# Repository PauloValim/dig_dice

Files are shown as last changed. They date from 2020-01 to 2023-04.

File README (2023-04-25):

Dado Digital usando CI´s da família TTL 74LS

A ideia deste projeto é servir como apoio às aulas da disciplina de circuitos digitais. Ao longo da disciplina, cada um dos blocos que compõem o dado digital será apresentado, de forma que, ao final, o aluno tenha um produto real e, além disso, tenha total entendimento de todos os detalhes do projeto.

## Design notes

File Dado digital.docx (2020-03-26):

Dado digital

Objetivo: implementar um circuito digital que permita efetuar o sorteio equivalente à face de um dado digital.

Descrição do projeto

Figura 1 – Diagrama de Blocos do Dado Digital

A Figura 1 ilustra o diagrama de blocos do Dado Digital. A base é um contador digital, que pode ser síncrono ou assíncrono, que efetua a contagem de 1 a 6 em binário. O bloco combinacional Decodificador é responsável por receber na entrado um valor binário entre 1 e 6 e gerar na saída o acionamento dos Leds correspondente a face de um dado. Para isto são usado 7 leds, conforme representado na figura 1. O circuito oscilador é responsável por gerar uma freqüência elevada (acima de 30 Hz) para que, uma vez fechada a CHAVE, o contador gere a sequência de 1 a 6 em uma velocidade que uma pessoa não consiga perceber que ela está ocorrendo (a impressão que se tem é que todos os leds estão ligados). Quando a chave é aberta o contador pára a contagem em um valor aleatório entre 1 e 6, equivalendo ao lançamento de um dado.

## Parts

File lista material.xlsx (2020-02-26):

Lista Material Dado Digital | característica encapsulamento | Quantidade
componente
74LS244 | CI/DIP | 1 | https://www.multcomercial.com.br/circuito-integrado-sn74ls244n-dip20-cod-loja-350-texas.html
74LS193 | CI/DIP | 1 | https://www.multcomercial.com.br/circuito-integrado-sn74ls193n-dip16-cod-loja-2141-fairchild.html
74LS10 | CI/DIP | 1 | https://www.multcomercial.com.br/circuito-integrado-sn74ls10n-dip14-renesas.html
74LS14 | CI/DIP | 1 | https://www.multcomercial.com.br/circuito-integrado-sn74ls14n-dip14-cod-loja-510-texas.html
MINI USB B SMD | conector USB/SMD | 1 | https://www.multcomercial.com.br/conector-mini-usb-femea-tipo-b-em-smd-5-vias-ds1104-b60sr.html
LED 5 mm |  | 7 | https://www.multcomercial.com.br/led-pisca-5mm-vermelho-difuso-l-517hd.html
150 ohms | resistor / SMD 0805 | 7 | https://www.multcomercial.com.br/resistor-smd-de-1-10-de-watt-0805-com-5-de-tolerancia-0r-a-10m.html
10 nF | capacitor SMD | 4 | http://sccomp.com.br/p-9307248-Capacitor-Ceramico-SMD-0805-10nF_50V-
22 pF | capacitor SMD | 1 | http://sccomp.com.br/p-9307254-Capacitor-Ceramico-SMD-0805-22pF_50V-
1k ohms | resistor / SMD 0805 | 1 | https://www.multcomercial.com.br/resistor-smd-de-1-10-de-watt-0805-com-5-de-tolerancia-0r-a-10m.html
chave tactil | 12x12x9.5 mm | 1 | https://www.baudaeletronica.com.br/chave-tactil-12x12x9-5mm-4-terminais.html
PCI | Placa Circuito Impresso

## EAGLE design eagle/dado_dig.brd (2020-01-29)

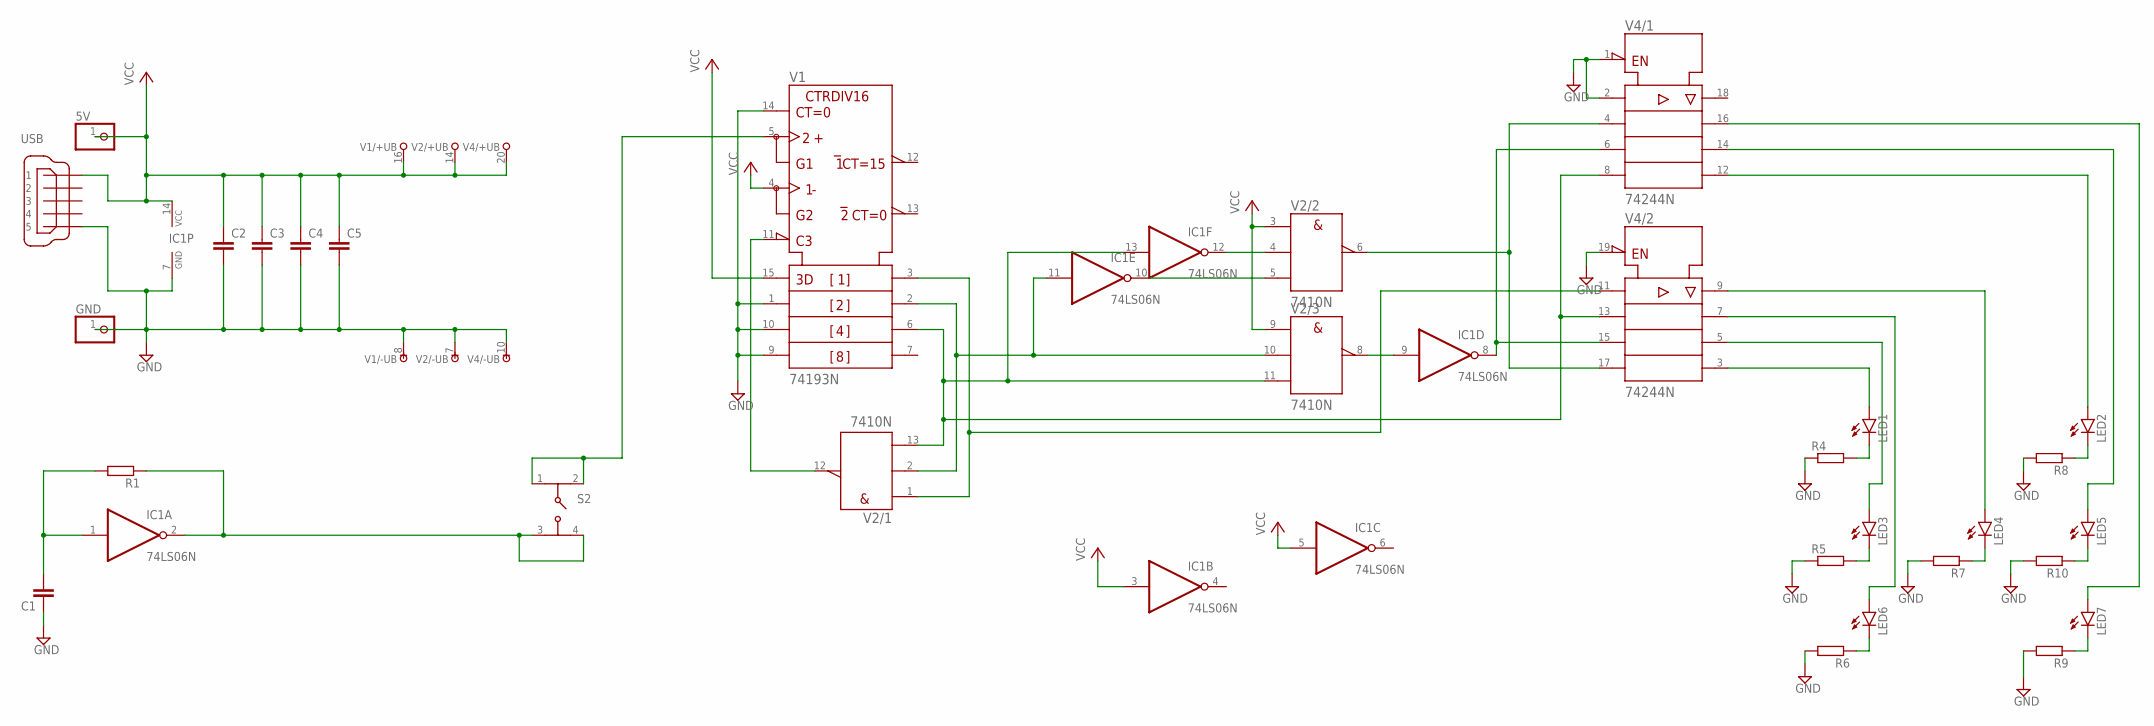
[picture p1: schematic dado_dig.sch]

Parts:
5V: PINHD-1X1; 1X01
C1, C2, C3, C4, C5: C-EUC0805K; C0805K
GND: PINHD-1X1; 1X01
IC1: 74LS06N; DIL14
LED1, LED2, LED3, LED4, LED5, LED6, LED7: LED5MM
R1, R4, R5, R6, R7, R8, R9, R10: R-EU_M0805; M0805
S2: 430456073736
USB: MINI-USB-32005-301; 32005-301
V1: 74193N; DIL16
V2: 7410N; DIL14
V4: 74244N; DIL20

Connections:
GND: C1.1, C2.2, C3.2, C4.2, C5.2, GND.1, IC1.7 (GND), R4.1, R5.1, R6.2, R7.2, R8.2, R9.2, R10.2, USB.5, V1.1 (B), V1.8 (-UB), V1.9 (D), V1.10 (C), V1.14 (CLR), V2.7 (-UB), V4.1 (!G), V4.2 (A1), V4.10 (-UB), V4.19 (!G)
unnamed: IC1.13 (I), V1.6 (QC), V2.11 (C), V2.13 (C), V4.8 (A4), V4.13 (A2)
unnamed: IC1.9 (I), V2.8 (Y)
unnamed: C1.2, IC1.1 (I), R1.2
unnamed: IC1.12 (O), V2.4 (B)
unnamed: IC1.2 (O), R1.1, S2.3 (2), S2.4
unnamed: V1.3 (QA), V2.1 (A), V4.11 (A1)
unnamed: IC1.10 (O), V2.5 (C)
unnamed: S2.1, S2.2 (3), V1.5 (UP)
unnamed: IC1.11 (I), V1.2 (QB), V2.2 (B), V2.10 (B)
unnamed: LED6.K (C), R6.1
unnamed: LED4.A, V4.9 (Y1)
unnamed: LED5.K (C), R10.1
unnamed: LED3.K (C), R5.2
unnamed: LED5.A, V4.14 (Y3)
unnamed: LED1.A, V4.3 (Y4)
unnamed: LED4.K (C), R7.1
unnamed: LED2.A, V4.12 (Y4)
unnamed: LED2.K (C), R8.1
unnamed: LED7.K (C), R9.1
unnamed: LED1.K (C), R4.2
unnamed: LED7.A, V4.16 (Y2)
unnamed: V1.11 (!LOAD), V2.12 (Y)
unnamed: LED6.A, V4.7 (Y2)
unnamed: V2.6 (Y), V4.4 (A2), V4.17 (A4)
unnamed: LED3.A, V4.5 (Y3)
unnamed: IC1.8 (O), V4.6 (A3), V4.15 (A3)
VCC: 5V.1, C2.1, C3.1, C4.1, C5.1, IC1.3 (I), IC1.5 (I), IC1.14 (VCC), USB.1, V1.4 (DOWN), V1.15 (A), V1.16 (+UB), V2.3 (A), V2.9 (A), V2.14 (+UB), V4.20 (+UB)

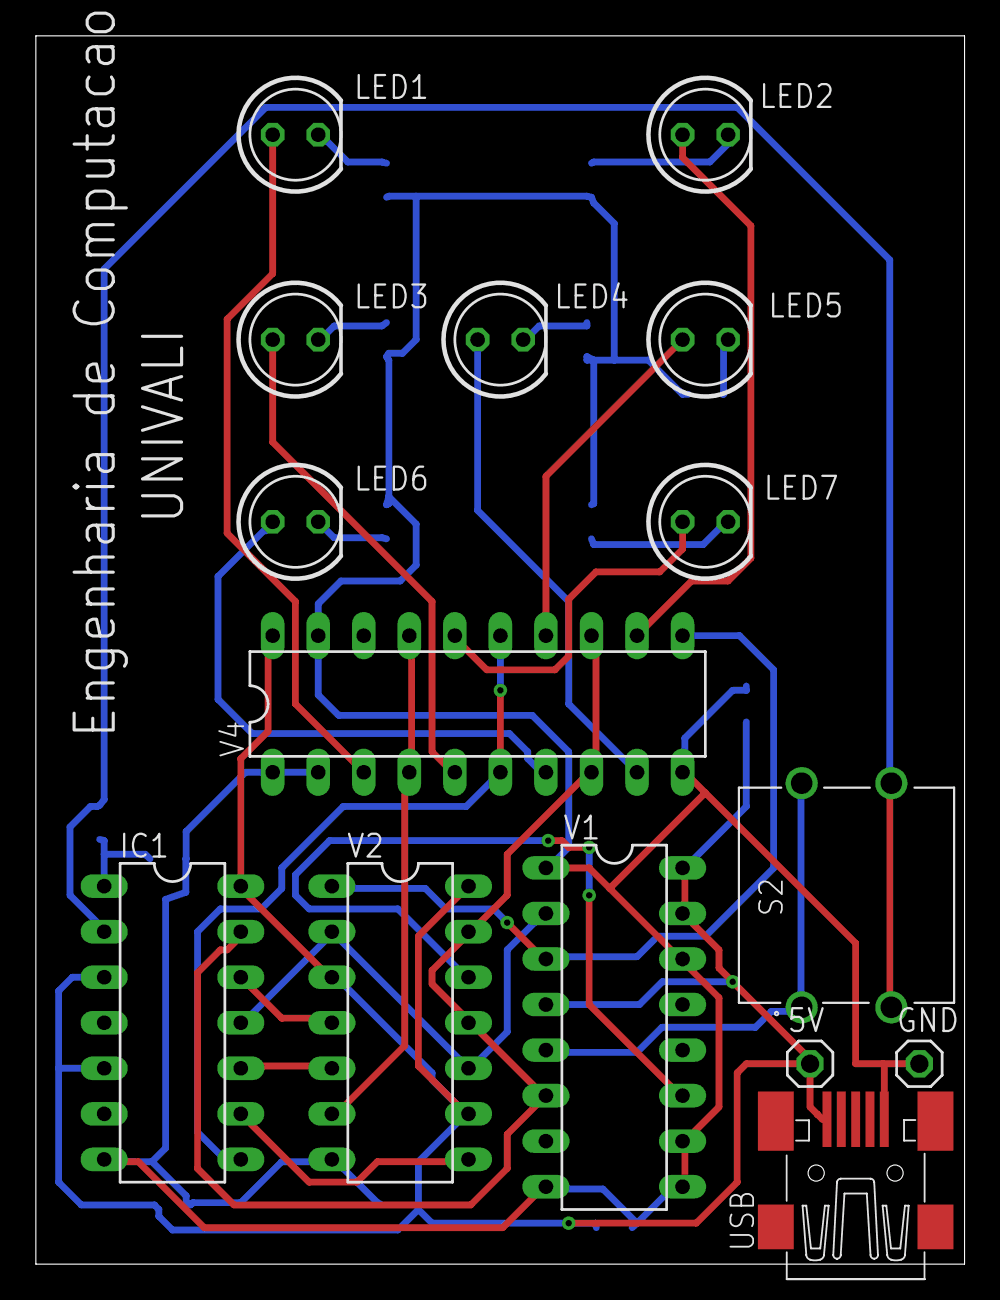
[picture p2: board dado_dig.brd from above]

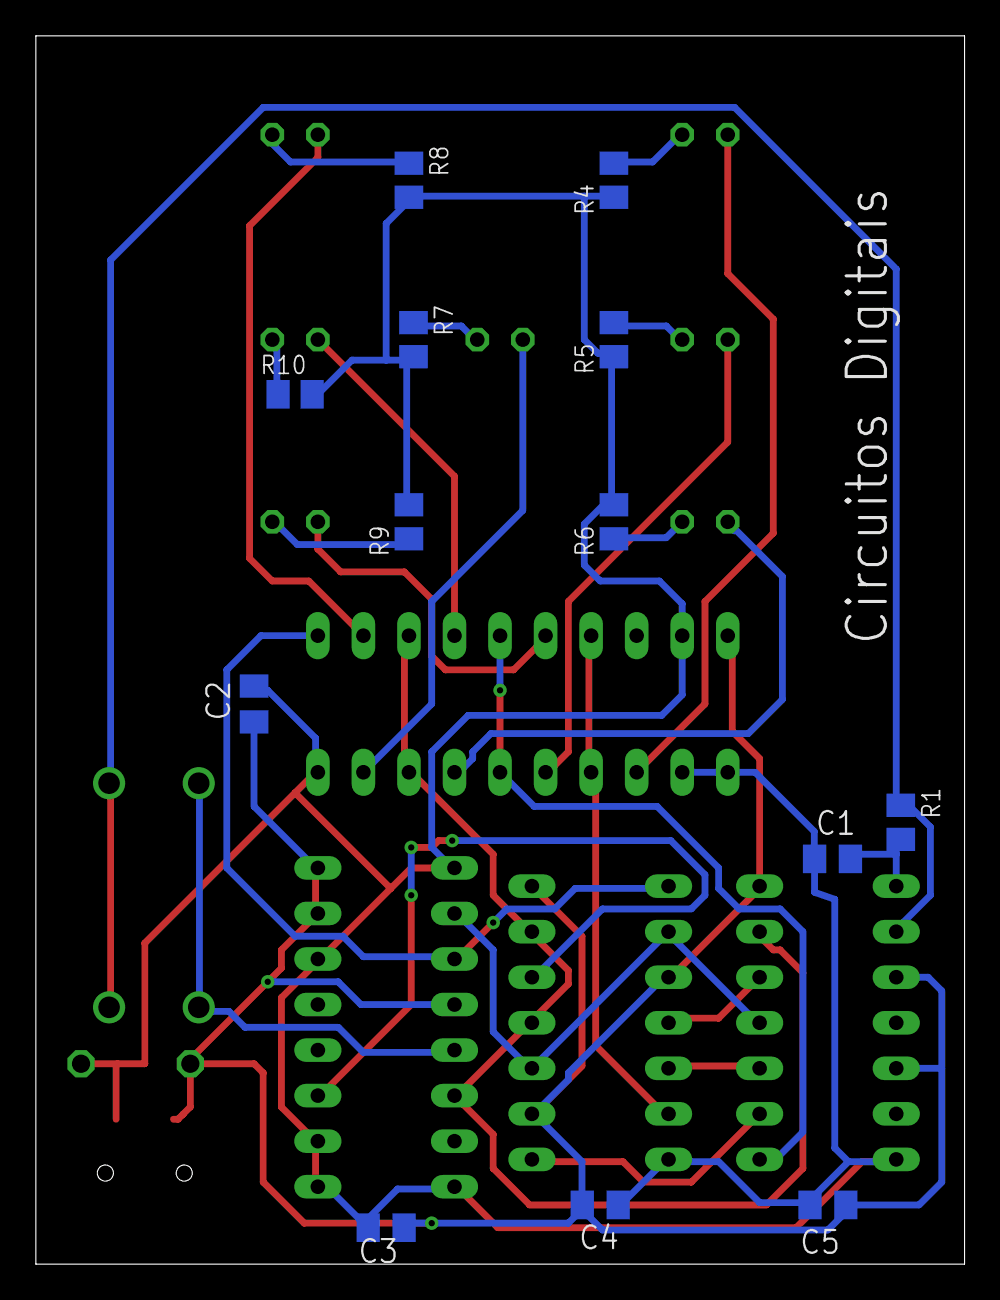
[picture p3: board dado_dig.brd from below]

Board: 2 copper layers, 51.8 x 68.5 mm, 28 parts (13 on the bottom side), 28 nets.

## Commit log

2020-01-29 versao inicial do projeto
    [dado_dig.brd, dado_dig.sch]
2020-02-26 inclusao lista material
    [lista material.xlsx]
2020-03-26 documento com descricao
    documento com a descricao baseada em diagrama de blocos
